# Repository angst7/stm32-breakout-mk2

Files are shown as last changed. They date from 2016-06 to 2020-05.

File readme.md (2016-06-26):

#STM32F4 development board#

ARMKit2 Breakout and development board for the 64-pin LQFP STM32F405 microcontroller.

The STM32F405 is a 32-bit ARM Cortex M4 micro manufactured by ST Microelectronics.

This PCB breaks out all the GPIO pins in two 2x16 pin 0.1" headers.  Power is provided by a USB mini-B connector through a 3.3v LDO regulator.  The USB data pins are routed to the port A USB peripheral in order to enable use of ST's built-in bootloader.  A Boot-select button is provided to enable this. 

The design is intended to be as bare-bones as possible, while enabling access to most of the important chip features.  Other features of this design are:

* Reset button.
* Two LEDs on-board.
* Optional External HS Oscillator
* Optional External RTC Oscillator
* Standard 6-Pin programming header for ST/Link
* 3mm mounting holes

Available as a shared project on [OSHPark](https://oshpark.com/profiles/MonkeyKungFu)

##Note regarding part population##

For STM32F405 parts, Populate C1 and C3 with 2.2uF capacitors.  Do not populate C5, R9.
For STM32F41x, STM32F4x1 parts, Populate R9 and C1 with 0 ohm Resistor.  Populate C5 with 4.7uF capacitor.  Do not populate C3.

##License##

This work is licensed under [CC Attribution 3.0 United States](https://creativecommons.org/licenses/by/3.0/us/).

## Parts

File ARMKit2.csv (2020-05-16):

Id | Designator | Package | Quantity | Designation | Supplier and ref
1 | U1 | LQFP-64_10x10mm_Pitch0.5mm | 1 | STM32F405RG
3 | D1,D4 | LED-0805 | 2 | LED
4 | D2 | SMD-1206_Pol | 1 | D
5 | SW2,SW1 | SW_SPST_FSMSM | 2 | SW_PUSH
6 | U2 | SOT-23-5 | 1 | LT1761
7 | P4 | USB_Mini-B | 1 | USB_B
8 | C14,C16,C2,C4,C10,C12 | SMD-0805 | 6 | .1uF
9 | C3,C1 | SMD-0805 | 2 | 2.2uF
10 | C5 | SMD-0805 | 1 | 4.7uF
11 | C6,C7,C8,C9 | SMD-0805 | 4 | 12pF
12 | C18 | SMD-0805 | 1 | 1uF
13 | C19 | SMD-0805 | 1 | 10nF
14 | C20 | SMD-0805 | 1 | 10uF
15 | P1 | Pin_Header_Straight_1x06 | 1 | CONN_01X06
16 | P2,P3 | Pin_Header_Straight_2x16 | 2 | CONN_01X32
17 | Y1 | Crystal_SMD_5032 | 1 | Crystal
18 | Y2 | SMD-1206_Pol | 1 | Crystal
19 | R1,R3 | SMD-0805 | 2 | 10k
20 | R2 | SMD-0805 | 1 | 0
21 | R4,R5 | SMD-0805 | 2 | 470
22 | R6,R7 | SMD-0805 | 2 | 1k
23 | R9 | SMD-0805 | 1 | DNP

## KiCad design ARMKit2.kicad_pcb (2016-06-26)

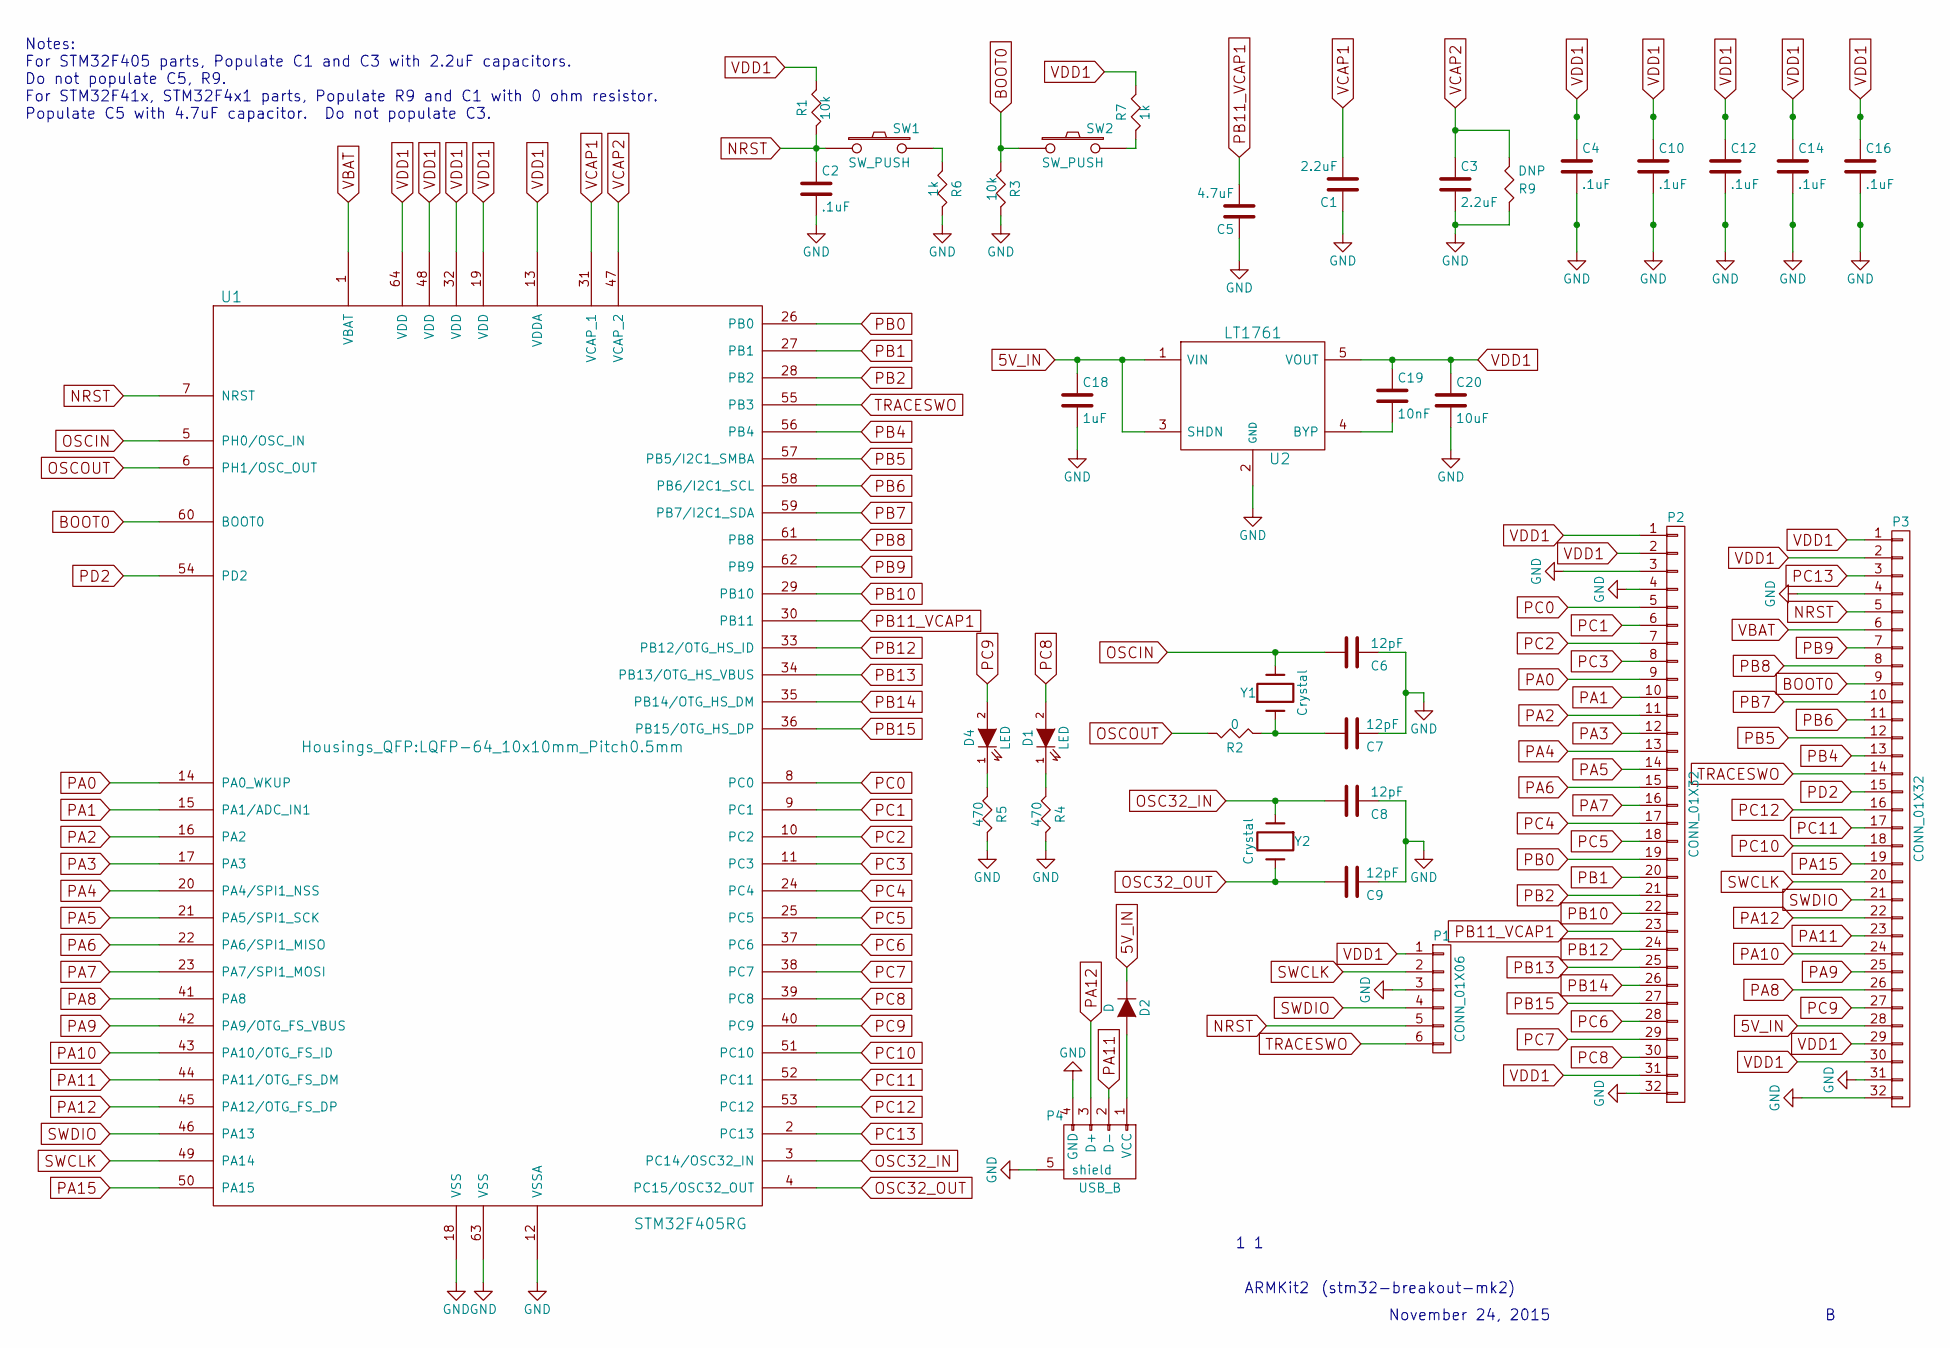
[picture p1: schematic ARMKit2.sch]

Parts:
C1, C3: 2.2uF; C_0805
C2, C4, C10, C12, C14, C16: .1uF; C_0805
C5: 4.7uF; C_0805
C6, C7, C8, C9: 12pF; C_0805
C18: 1uF; C_1210
C19: 10nF; C_0805
C20: 10uF; C_1210
D1, D4: LED; LED-0805
D2: D; SMD-1206_Pol
P1: CONN_01X06; Pin_Header_Straight_1x06
P2, P3: CONN_01X32; Pin_Header_Straight_2x16
P4: USB_B; USB_Mini-B
R1, R3: 10k; C_0805
R2: 0; C_0805
R4, R5: 470; C_0805
R6, R7: 1k; C_0805
R9: DNP; C_0805
SW1, SW2: SW_PUSH; SW_SPST_FSMSM
U1: STM32F405RG; LQFP-64_10x10mm_Pitch0.5mm
U2: LT1761; SOT-23-5
Y1: Crystal; Crystal_SMD_5032_2Pads
Y2: Crystal; SMD-1206_Pol

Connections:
5V_IN: C18.1, D2.1 (K), P3.28, U2.1 (VIN), U2.3 (SHDN)
BOOT0: P3.9, R3.1, SW2.1, U1.60 (BOOT0)
GND: C1.1, C2.2, C3.2, C4.2, C5.1, C6.1, C7.1, C8.1, C9.1, C10.2, C12.2, C14.2, C16.2, C18.2, C20.2, P1.3, P2.3, P2.4, P2.32, P3.4, P3.31, P3.32, P4.4 (GND), P4.5 (shield), R3.2, R4.2, R5.2, R6.2, R9.2, U1.12 (VSSA), U1.18 (VSS), U1.63 (VSS), U2.2 (GND)
NRST: C2.1, P1.5, P3.5, R1.1, SW1.1, U1.7 (NRST)
unnamed: C7.2, R2.1, Y1.1
unnamed: C19.2, U2.4 (BYP)
unnamed: D1.1 (K), R4.1
unnamed: D2.2 (A), P4.1 (VCC)
unnamed: D4.1 (K), R5.1
unnamed: R6.1, SW1.2
unnamed: R7.1, SW2.2
OSC32_IN: C8.2, U1.3 (PC14/OSC32_IN), Y2.1
OSC32_OUT: C9.2, U1.4 (PC15/OSC32_OUT), Y2.2
OSCIN: C6.2, U1.5 (PH0/OSC_IN), Y1.2
OSCOUT: R2.2, U1.6 (PH1/OSC_OUT)
PA0: P2.9, U1.14 (PA0_WKUP)
PA1: P2.10, U1.15 (PA1/ADC_IN1)
PA2: P2.11, U1.16 (PA2)
PA3: P2.12, U1.17 (PA3)
PA4: P2.13, U1.20 (PA4/SPI1_NSS)
PA5: P2.14, U1.21 (PA5/SPI1_SCK)
PA6: P2.15, U1.22 (PA6/SPI1_MISO)
PA7: P2.16, U1.23 (PA7/SPI1_MOSI)
PA8: P3.26, U1.41 (PA8)
PA9: P3.25, U1.42 (PA9/OTG_FS_VBUS)
PA10: P3.24, U1.43 (PA10/OTG_FS_ID)
PA11: P3.23, P4.2 (D-), U1.44 (PA11/OTG_FS_DM)
PA12: P3.22, P4.3 (D+), U1.45 (PA12/OTG_FS_DP)
PA15: P3.19, U1.50 (PA15)
PB0: P2.19, U1.26 (PB0)
PB1: P2.20, U1.27 (PB1)
PB2: P2.21, U1.28 (PB2)
PB4: P3.13, U1.56 (PB4)
PB5: P3.12, U1.57 (PB5/I2C1_SMBA)
PB6: P3.11, U1.58 (PB6/I2C1_SCL)
PB7: P3.10, U1.59 (PB7/I2C1_SDA)
PB8: P3.8, U1.61 (PB8)
PB9: P3.7, U1.62 (PB9)
PB10: P2.22, U1.29 (PB10)
PB11_VCAP1: C5.2, P2.23, U1.30 (PB11)
PB12: P2.24, U1.33 (PB12/OTG_HS_ID)
PB13: P2.25, U1.34 (PB13/OTG_HS_VBUS)
PB14: P2.26, U1.35 (PB14/OTG_HS_DM)
PB15: P2.27, U1.36 (PB15/OTG_HS_DP)
PC0: P2.5, U1.8 (PC0)
PC1: P2.6, U1.9 (PC1)
PC2: P2.7, U1.10 (PC2)
PC3: P2.8, U1.11 (PC3)
PC4: P2.17, U1.24 (PC4)
PC5: P2.18, U1.25 (PC5)
PC6: P2.28, U1.37 (PC6)
PC7: P2.29, U1.38 (PC7)
PC8: D1.2 (A), P2.30, U1.39 (PC8)
PC9: D4.2 (A), P3.27, U1.40 (PC9)
PC10: P3.18, U1.51 (PC10)
PC11: P3.17, U1.52 (PC11)
PC12: P3.16, U1.53 (PC12)
PC13: P3.3, U1.2 (PC13)
PD2: P3.15, U1.54 (PD2)
SWCLK: P1.2, P3.20, U1.49 (PA14)
SWDIO: P1.4, P3.21, U1.46 (PA13)
TRACESWO: P1.6, P3.14, U1.55 (PB3)
VBAT: P3.6, U1.1 (VBAT)
VCAP1: C1.2, U1.31 (VCAP_1)
VCAP2: C3.1, R9.1, U1.47 (VCAP_2)
VDD1: C4.1, C10.1, C12.1, C14.1, C16.1, C19.1, C20.1, P1.1, P2.1, P2.2, P2.31, P3.1, P3.2, P3.29, P3.30, R1.2, R7.2, U1.13 (VDDA), U1.19 (VDD), U1.32 (VDD), U1.48 (VDD), U1.64 (VDD), U2.5 (VOUT)

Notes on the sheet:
ARMKit2
November 24, 2015
(stm32-breakout-mk2)
Notes: For STM32F405 parts, Populate C1 and C3 with 2.2uF capacitors. Do not populate C5, R9. For STM32F41x, STM32F4x1 parts, Populate R9 and C1 with 0 ohm resistor. Populate C5 with 4.7uF capacitor. Do not populate C3.

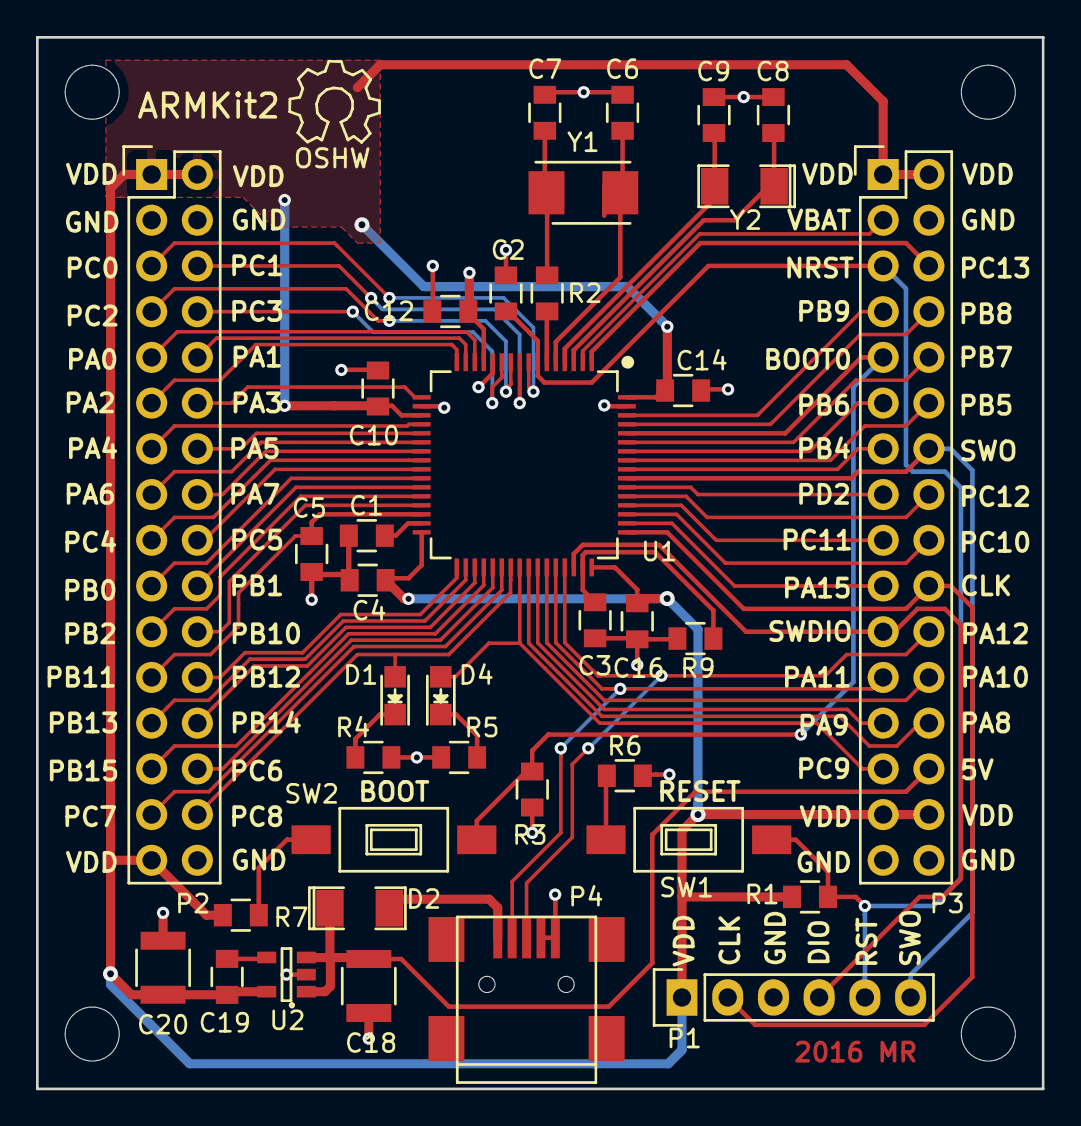
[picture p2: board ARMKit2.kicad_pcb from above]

Board: 2 copper layers, 55.9 x 58.4 mm, 37 parts (0 on the bottom side), 66 nets.

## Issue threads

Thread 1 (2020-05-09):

R7 specification

petrohi, 2020-05-09:
The BOM specifies R7 as 10k, while the schematics specifies 1k.

Which is it?

angst7, 2020-05-09:
R7 should be 1k.

Closed 2020-05-16.

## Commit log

2015-10-23 Added a bunch of traces
    [ARMKit2.kicad_pcb]
2015-10-23 More layout work.
    [ARMKit2.kicad_pcb]
2015-10-24 Finalized PCB
    [ARMKit2.kicad_pcb]
2015-11-11 Added some detail on the silk layer
    [ARMKit2.kicad_pcb]
2015-11-16 Added VBAT to breakout header, cleaned up RES fp size, cleaned up silkscreen
    [ARMKit2-NPTH.drl, ARMKit2.gbl, ARMKit2.gbo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]
2015-11-16 Fixed broken track
    [ARMKit2-B_Cu.gbr, ARMKit2-B_Mask.gbr, ARMKit2-B_SilkS.gbr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]
2015-11-16 Removed some untracked files, updated gitignore
    [ARMKit2.drl, ARMKit2.gbl, ARMKit2.gbo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]
2015-11-17 Moved USB to PA11/PA12
    [ARMKit2.kicad_pcb, ARMKit2.sch]
2015-11-17 Added BOOT and RESET buttons, much re-routing
    [ARMKit2.kicad_pcb, ARMKit2.sch]
2015-11-24 Cleaned up some unused caps, added CC Attribution license
    [ARMKit2.kicad_pcb, ARMKit2.sch]
2015-11-24 Updated Gerbers to new name format
    [ARMKit2-B.Cu.gbr, ARMKit2-B.Mask.gbr, ARMKit2-B.SilkS.gbr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]
2015-11-25 More small changes to PCB, Schematic. Gerber refresh
    [ARMKit2-B.Cu.gbr, ARMKit2-B.Mask.gbr, ARMKit2-B.SilkS.gbr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]
2015-11-25 Moved traces that were too close to through-hole headers. Thanks @_madworm_
    [ARMKit2-B.Cu.gbr, ARMKit2-B.Mask.gbr, ARMKit2-B.SilkS.gbr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]
2015-12-07 Updated some 3d model settings
    [ARMKit2-B.Cu.gbr, ARMKit2-B.Mask.gbr, ARMKit2-B.SilkS.gbr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]
2015-12-19 Fixed BOOT0 pullup resistor value
    [ARMKit2.sch]
2016-03-18 Added BOM
    [ARMKit2.csv]
2016-06-24 Added STM32F411, LTC6234
2016-06-25 Updated for STM32F41x, STM32F4x1 compatibility
    [ARMKit2.csv, ARMKit2.kicad_pcb, ARMKit2.sch]
2016-06-25 Added population notes
    [ARMKit2.sch]
2016-06-26 Moved outline, can direct upload to OSHPark
    [ARMKit2.kicad_pcb, ARMKit2.sch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]
2020-05-16 R7 1k
    [ARMKit2.csv]
